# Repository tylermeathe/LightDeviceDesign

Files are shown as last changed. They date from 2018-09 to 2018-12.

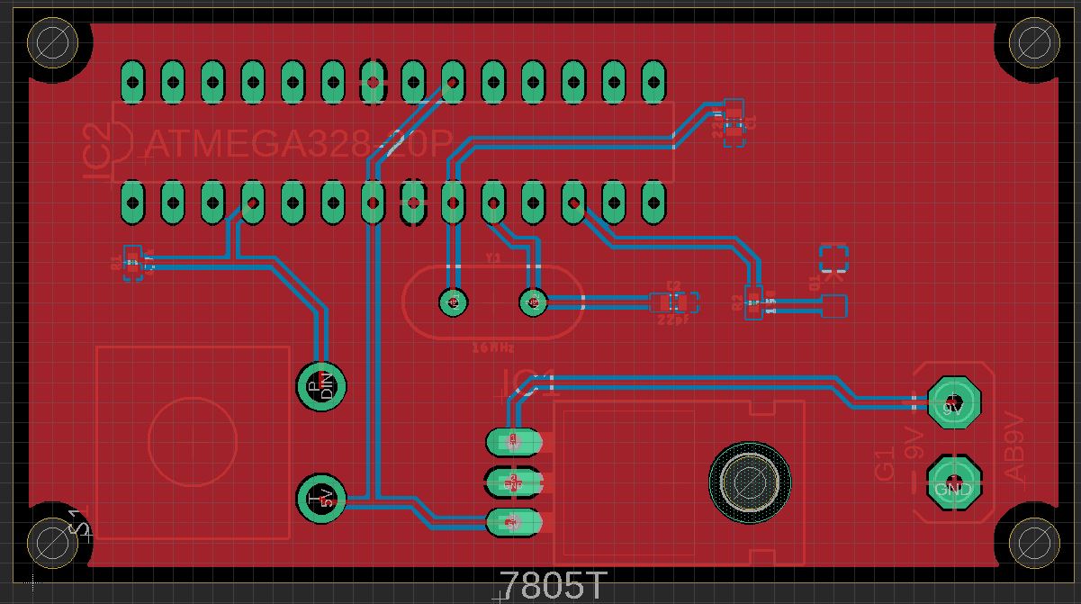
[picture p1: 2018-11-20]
Electronics/PCB Updated.JPG

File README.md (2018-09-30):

# LightDeviceDesign
This read me file is a description of the project.

In this project, one needs to create a light device that functions under different conditions. The light must be able to turn off, turn on at a bright level, be on at an intermediate bright level, be on at a least bright level, and also be on in 2 Hz intervals. The device should be protected by its casing and able to withstand a 3 ft fall as well.

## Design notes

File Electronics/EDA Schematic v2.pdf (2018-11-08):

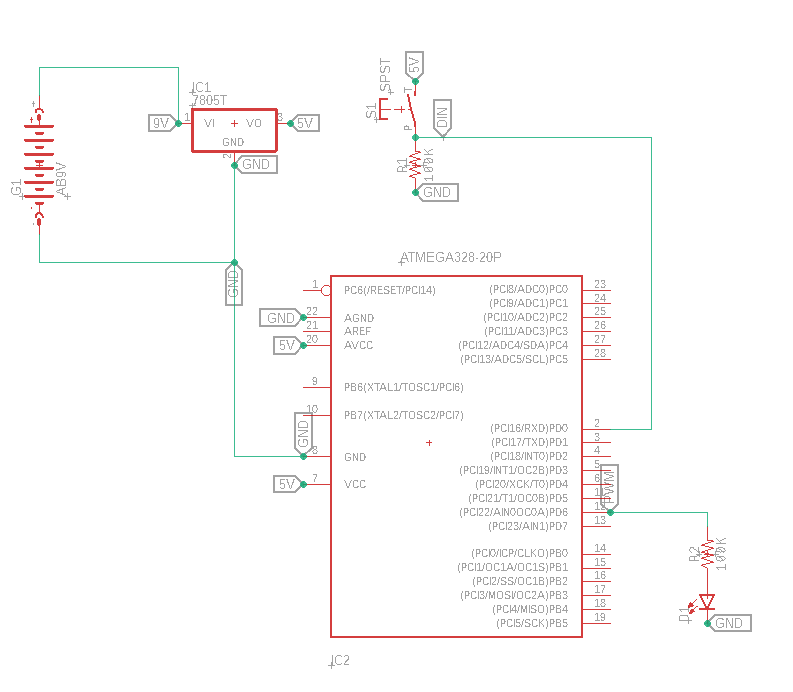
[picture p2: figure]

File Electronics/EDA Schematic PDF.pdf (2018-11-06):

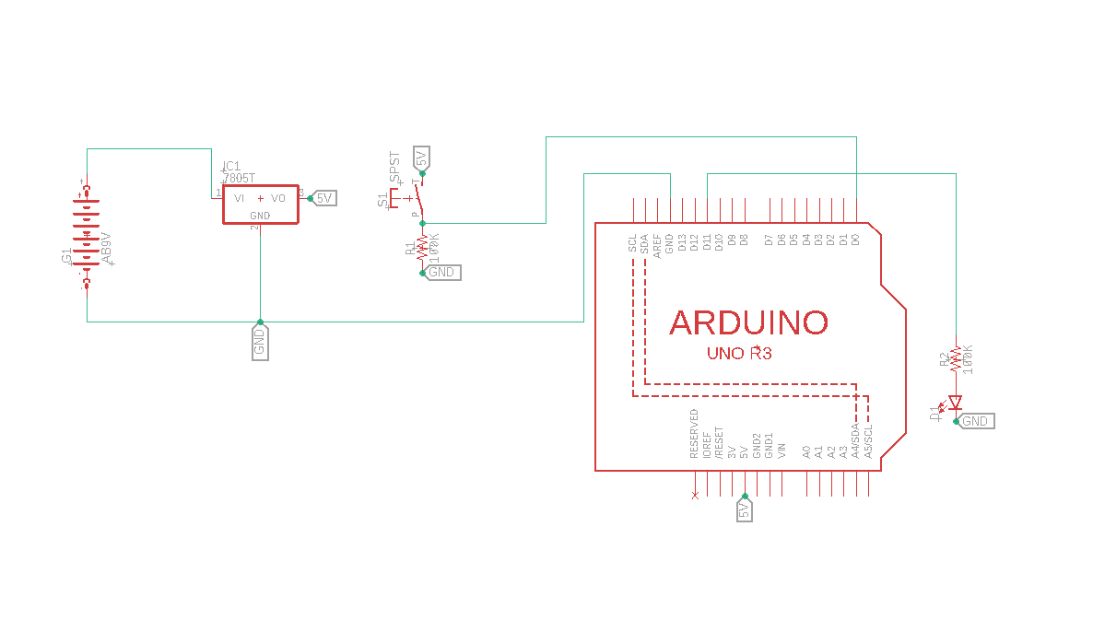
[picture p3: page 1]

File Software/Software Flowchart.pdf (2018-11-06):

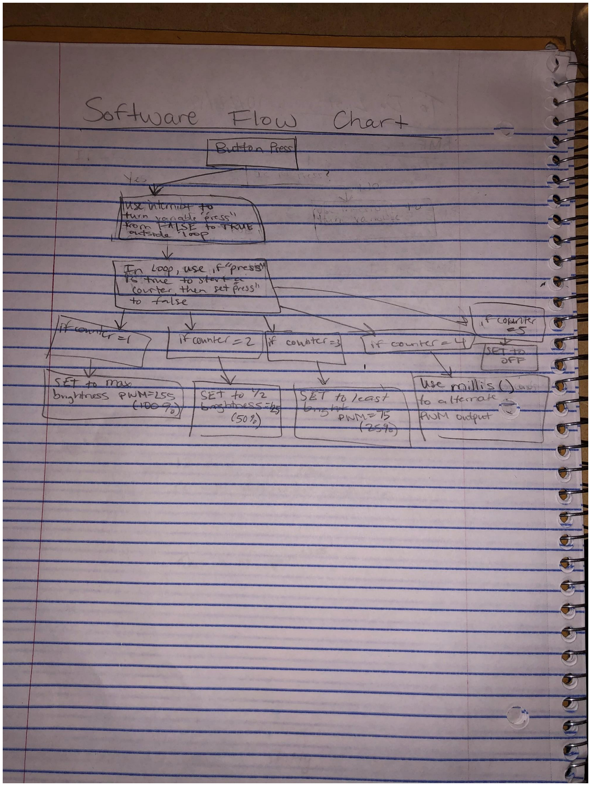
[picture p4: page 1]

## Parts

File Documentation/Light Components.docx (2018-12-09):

Light Device Components

1. 2- 22 pF capacitors
2. 16MHz crystal oscillator
3. 150 ohm resistor
4. 4.7k ohm resistor
5. LED
6. ATMega328p
7. 7805T 5 Volt Voltage Regulator
8. Button
9. Protoboard (PCB was inoperable)

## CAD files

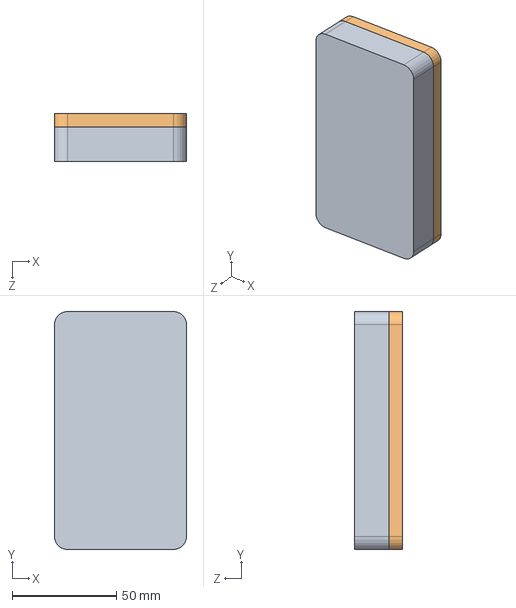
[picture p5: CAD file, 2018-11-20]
Mechanical/Light Assembly.SLDASM
63.5 x 114.3 x 22.9 mm
Light Device Bottom
Light Device Top

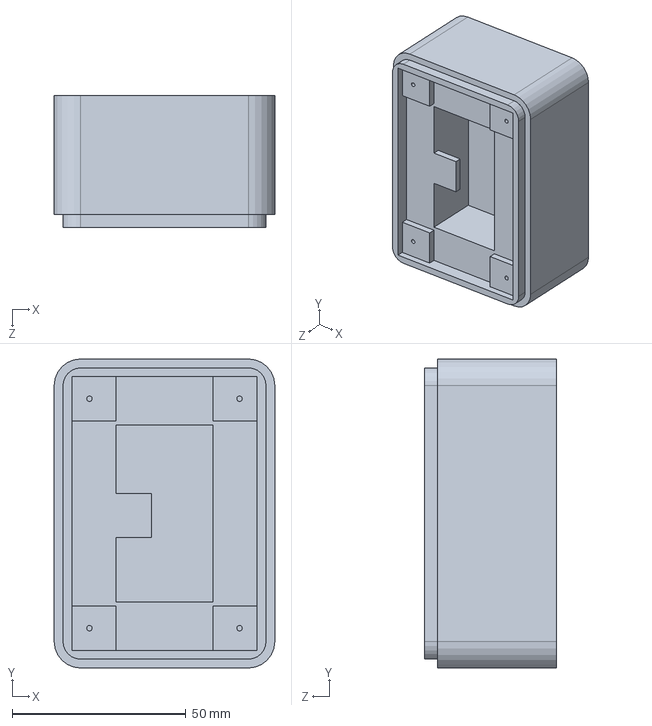
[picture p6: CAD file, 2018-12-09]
Mechanical/Light bottom.SLDPRT
63.5 x 88.9 x 38.1 mm

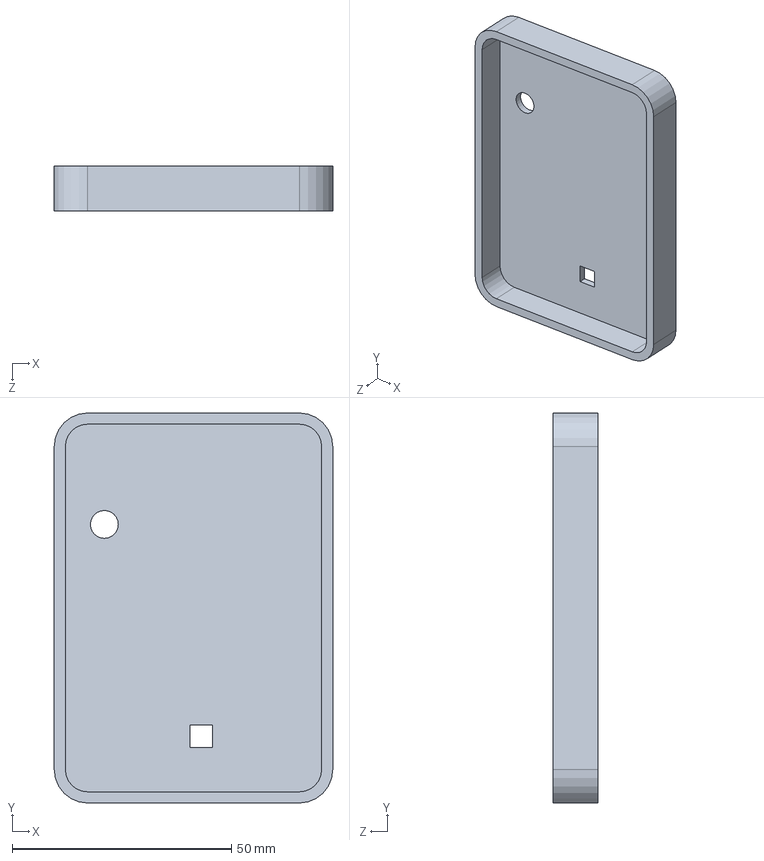
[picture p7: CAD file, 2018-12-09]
Mechanical/light top.SLDPRT
63.5 x 88.9 x 10.2 mm

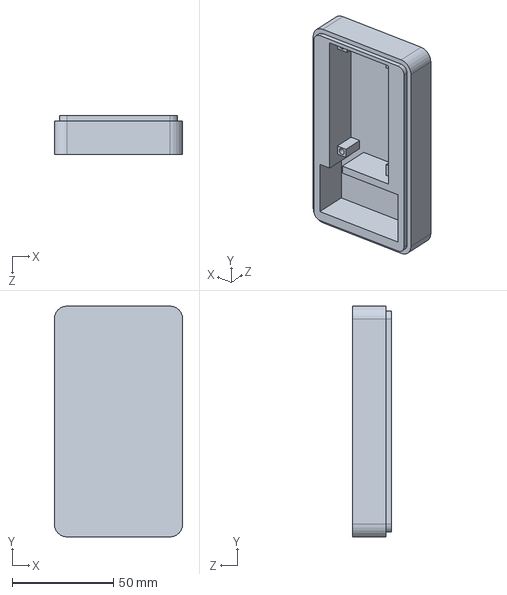
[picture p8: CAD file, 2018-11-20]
Mechanical/Light Device Bottom.SLDPRT
63.5 x 114.3 x 19.1 mm

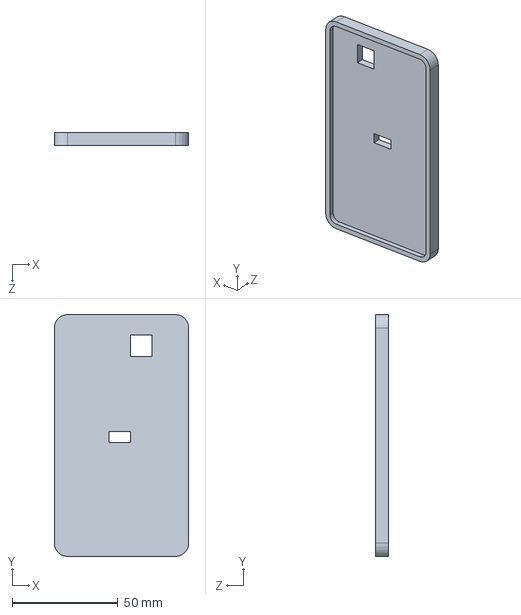
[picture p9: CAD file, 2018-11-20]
Mechanical/Light Device Top.SLDPRT
63.5 x 114.3 x 6.35 mm

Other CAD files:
Mechanical/Light bottom.SLDDRW
Mechanical/Light bottom.STL
Mechanical/light top.SLDDRW
Mechanical/light top.STL

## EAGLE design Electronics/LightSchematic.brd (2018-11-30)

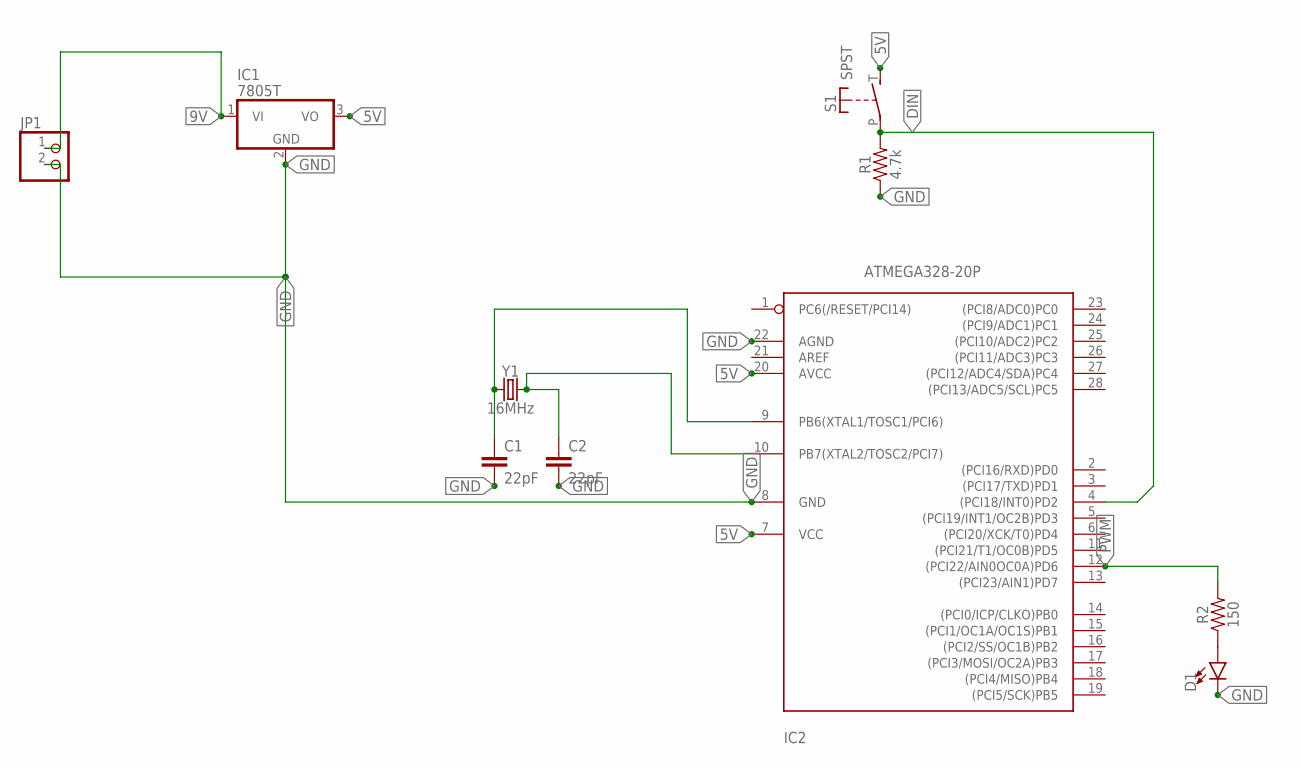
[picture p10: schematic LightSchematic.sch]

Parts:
C1, C2: 22pF; 0603
D1: LED1206; LED-1206
IC1: 7805T; TO220H
IC2: ATMEGA328-20P; DIL28-3
JP1: PINHD-1X2; 1X02
R1: 4.7k; 0402
R2: 150; 0402
S1: SPST; JUDCOSPST
Y1: 16MHz; HC49US

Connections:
5V: IC1.3 (VO), IC2.7 (VCC), IC2.20 (AVCC), S1.T (S)
9V: IC1.1 (VI), JP1.1
DIN: IC2.4 ((PCI18/INT0)PD2), R1.2, S1.P
GND: C1.2, C2.2, D1.C, IC1.2 (GND), IC2.8 (GND), IC2.22 (AGND), JP1.2, R1.1
unnamed: C1.1, IC2.9 (PB6(XTAL1/TOSC1/PCI6)), Y1.1
unnamed: C2.1, IC2.10 (PB7(XTAL2/TOSC2/PCI7)), Y1.2
unnamed: D1.A, R2.1
PWM: IC2.12 ((PCI22/AIN0OC0A)PD6), R2.2

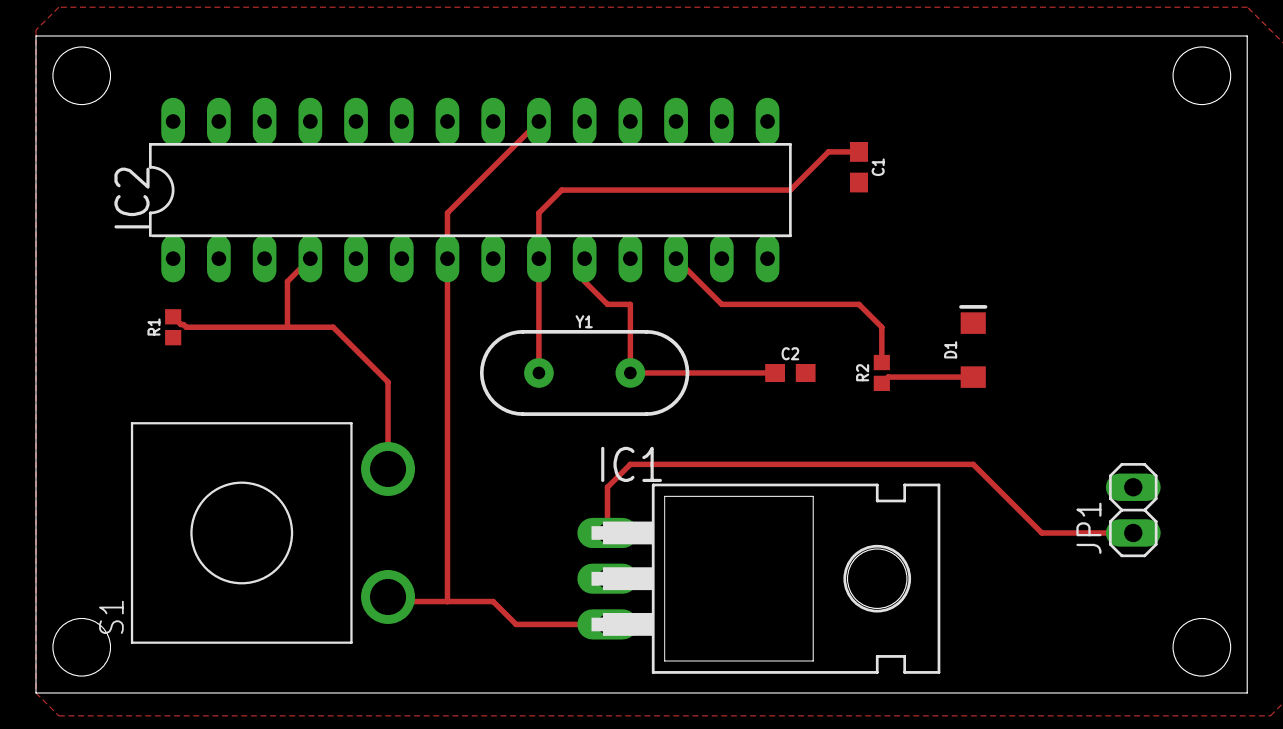
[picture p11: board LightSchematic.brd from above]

Board: 2 copper layers, 67.3 x 36.5 mm, 10 parts (0 on the bottom side), 8 nets.

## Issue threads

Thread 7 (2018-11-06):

Review Milestone 3 Release

tylermeathe, 2018-11-06:
Hi Dr. Palmeri,
I didn't realize that we were supposed to add and assign our schematic and flowchart to github for your review for milestone 3, so I have just added and made a release of those deliverables for your review.

Sorry about just now adding those!
Tyler

mlp6, 2018-11-08:
Looking good... make sure that you capture the battery in the schematic not as a battery, but as the connections you need to make to the battery!

Closed 2018-11-08.

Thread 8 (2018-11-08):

Review Milestone 4 Release

tylermeathe, 2018-11-08:
Dr. Palmeri,

I just uploaded my v0.2.0 release for milestone 4.

I have changed the schematic from Milestone 3 slightly to include the atmega328 chip instead of the shield and have uploaded the board and software for the device for your review.

Thanks,
Tyler

tylermeathe, 2018-11-18:
@mlp6

Hi Dr. Palmeri,

I never received a review on my ECAD and software release and I was just trying to see if you guys can look at it before I start finalizing my mechanical design.

Thanks!
Tyler

mlp6, 2018-11-19:
Brinnae was helping review these, but I see that she and Matt Brown were never added as Collaborators on the project; can you add them now?

mlp6, 2018-11-19:
I just took a quick look:
* I think that you'll need a crystal on the board if you are just using the `ATMEGA328`; I think you should be able to find a 16 MHz crystal oscillator in the parts library.
* It doesn't look like the negative lead of your battery is attached to anything, nor is the `GND` connection of your voltage regulator... or actually anything that should be attached to `GND`.  It looks like those connections are not correctly made in the schematic, which is why you didn't get ratlines for those traces.

tylermeathe, 2018-11-19:
Thanks for looking over @mlp6 !

I think my ground is correctly set up, at least when I look at it. I uploaded a picture below. I have both the top and bottom layer set as GND.

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

For the ATMEGA328, how do you incorporate the crystal into the board. Is there a specific pin that the crystal should be going into?

What is Matt Brown's username? I added Brinnae but she hasn't accepted it yet.

Closed 2018-11-20.

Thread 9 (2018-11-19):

Review PCB

tylermeathe, 2018-11-19:
Hi Matt,

I was hoping you could review my PCB. Dr. Palmeri recently looked it over but he had mentioned the need for a 16 MHz crystal oscillator for the ATMEGA328p chip. I have never really worked with this microcontroller, so I am a little confused in where I should be placing this crystal and how it will work with the microcontroller.

If you could give me some feedback, I would appreciate it!

Thanks,

Tyler

sphaerobolus, 2018-11-20:
All microcontrollers need a clock. The clock sort of "turns the crank" to make the microcontroller work; almost everything that happens, happens on a clock tick.

The Uno board has a crystal oscillator for its clock. If you want your ATMega328 to work off the Uno board, you need to provide a a crystal. The crystal connects between pins 9 and 10 of the '328. You'll also need a small capacitor to ground on each of the crystal pins. Check this out:

https://www.arduino.cc/en/Tutorial/ArduinoToBreadboard

tylermeathe, 2018-11-20:
@sphaerobolus
Hi Matt,

I am trying to look for the library for the 9B-16.000MEEJ-B crystal, but I am not seeing it anywhere for download. Do you have this library to share with me?

sphaerobolus, 2018-11-20:
In the Crystal library, there's HC49/S. That's the right size and thus is good enough.

tylermeathe, 2018-11-20:
I've updated my pcb to have all of the new components if you want to take a look. Let me know if this looks good!

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

sphaerobolus, 2018-11-28:
It does look good.

Closed 2018-11-29.

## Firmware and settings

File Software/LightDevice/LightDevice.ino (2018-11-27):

// use preprocessor directives to define constants in the code
#define BUTTON_IN 2
#define LED_OUT 6
#define PWM_MAX 255

// global variables representing "state" across all functions
// operating mode: 0 - off, 1 - bright, 2 - mid-bright, 3 - dim, 4 - flash
int operating_mode = 0;
int button_state = 0;
int previous_button_state = 0;
int PWM_OUT = 0;

unsigned long PrevTime = 0;
unsigned long lag_time = 0;
int lag_delay = 250;

bool BUTTON_PUSHED = false;

// executed one-time at device startup
void setup() {
   attachInterrupt(digitalPinToInterrupt(BUTTON_IN), button_pushed, FALLING);
 // define output (PWM) pin connected to LED
  pinMode(LED_OUT, OUTPUT);
}

// continually-running loop
// calls functions that are named as "actions"
void loop() {
  check_button_press();

  set_pwm_based_on_operating_mode();

  shine_led();

}

void set_pwm_based_on_operating_mode() {

  switch (operating_mode) {
    case 0:
      PWM_OUT = 0;
      break;
    case 1:
      PWM_OUT = PWM_MAX;
      break;
    case 2:
      PWM_OUT = int(PWM_MAX / 2);
      break;
    case 3:
      PWM_OUT = int(PWM_MAX / 4);
      break;
    case 4:
    flash_the_light();
      break;
  }

}

void button_pushed() {
  BUTTON_PUSHED = true;
}

void flash_the_light() {
  unsigned long CurrentTime = millis();
  if(CurrentTime - PrevTime >= 500){
    PrevTime = CurrentTime;
    if (PWM_OUT == 0){
      PWM_OUT=PWM_MAX;
    }else{
      PWM_OUT=0;
    }
  }
}

void shine_led() {
  analogWrite(LED_OUT, PWM_OUT);
}

void check_button_press() {
  if (BUTTON_PUSHED == true) {
    if (millis() - lag_time > lag_delay) {
      operating_mode = operating_mode + 1;
      if (operating_mode == 5) {
        operating_mode = 0;
      }
      lag_time = millis();
    }
  }
  BUTTON_PUSHED = false;
}

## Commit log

2018-11-06 Add EDA schematic PDF to Repo
2018-11-06 Add flowchart to software repo
2018-11-08 Add updated schematic with ATMEGA328p
2018-11-08 Add Eagle Project to repo for milestone 4 review
    [LightSchematic.brd, LightSchematic.sch]
2018-11-08 Add v0.2.0 board and schematic for milestone 4
    [LightSchematic.brd]
2018-11-08 Add v0.2.1 for milestone 4 review
    [LightSchematic.brd, LightSchematic.sch]
2018-11-08 add Arduino software v0.2.0
2018-11-19 Added holes to PCB
    [LightSchematic.brd]
2018-11-20 Add solidworks casing design
    [Light Assembly.SLDASM, Light Device Bottom.SLDPRT, Light Device Top.SLDPRT]
2018-11-20 Added 16 MHz crystal oscillator and 2 22 pF capacitors
    [LightSchematic.brd, LightSchematic.sch]
2018-11-20 Add JPG of Board
2018-12-09 New Casing for Protoboard
    [Light bottom.SLDPRT, Light bottom.STL, light top.SLDPRT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]
2018-12-14 Add drawings to repo
    [Light bottom.SLDDRW, light top.SLDDRW]

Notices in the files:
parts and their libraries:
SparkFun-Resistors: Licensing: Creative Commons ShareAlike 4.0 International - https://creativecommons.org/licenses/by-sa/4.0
